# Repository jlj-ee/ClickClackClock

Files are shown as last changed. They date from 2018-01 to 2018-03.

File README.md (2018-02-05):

# ClickClackClock
This was a hobby project to create an impractically loud and large clock constructed from salvaged electromechanical seven-segment flip digits (also known as vane displays). To be slightly less obnoxious, the clock automatically sleeps in dark rooms, and wakes up with the correct time when exposed to light -- great for people who like to wake up with the dawn! 
<!--- The clock can also be put into a countdown/stopwatch mode, appropriate for games, New Year's Eve, the apocalypse, etc. --->

The [flip digits](http://www.scoretronics.com/components/Digits_Brochure.pdf) came from a retired aquatics scoreboard/timing system. The segments change position when current is pulsed through a magnetic coil. 

## Software
__Required dependencies:__

**_More info TBA_**

## CAD Contents
We designed custom 2-layer PCBs for this project using [Eagle](https://www.autodesk.com/products/eagle/overview) and fabbed them using [OSHPark](https://oshpark.com/), with all through-hole components for ease of assembly:
- __clock_driver_board:__ Drives a single digit, and can be daisy-chained together for as many digits as needed.
- __clock_motherboard:__ Slightly larger than the Arduino UNO but with the same microcontroller and pad layout for future shield compatibility. Integrates the standard DS1307 RTC on the board and controls the whole system - digit drivers, buttons, photoresistor, etc.
- __clock_system:__ Schematic that describes the overall system of PCBs and auxiliary components.

## Assembly
The digits are supported in a frame made from MDF. 

**_More info TBA_**

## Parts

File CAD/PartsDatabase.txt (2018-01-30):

Mfg Part Num	Mfg Name	VID	Vendor Part Num	Description	Pkg Code
EEU-TP1E202S	Panasonic	ME	667-EEU-TP1E202S	Aluminum Electrolytic Capacitors - Leaded Aluminum Electrolytic Capacitors - Leaded 2000uF 25volts AEC-Q200	
CFR-25JR-52-470R	Yageo	ME	603-CFR-25JR-52470R	Carbon Film Resistors - Through Hole Carbon Film Resistors - Through Hole 470ohm 1/4W 5%	
1546551-3	TE Connectivity	ME	571-1546551-3	"Fixed Terminal Blocks 3P,STRAIGHT SIDE ENTRY,3.5MM"	
826631-4	TE Connectivity	ME	571-826631-4	Headers & Wire Housings 1X04 POS R/A AU	
21RZ310-RC	Xicon	ME	21RZ310-RC	Multilayer Ceramic Capacitors MLCC - Leaded .1uF 50volts Z5U 20% 2.5mm L/S	
CD74HC4050E	Texas Instruments	ME	595-CD74HC4050E	Buffers & Line Drivers Hex Non-Inverting	
MIC5891YN	Microchip Technology / Micrel	ME	998-MIC5891YN	Latches 8-Bit Serial Input Latched Driver	
WP7113SRD/D	Kingbright	ME	604-WP7113SRD/D	Standard LEDs - Through Hole RED DIFFUSED	
ATMEGA328P-PU	Microchip Technology / Atmel	ME	556-ATMEGA328P-PU	8-bit Microcontrollers - MCU 32KB In-system Flash 20MHz 1.8V-5.5V	
4828-3004-CP	3M	ME	517-4828-3004-CP	"IC & Component Sockets SOCKET 28POS .3"" IC OPEN FRAME"	
DS1307+	Maxim Integrated	ME	700-DS1307	Real Time Clock 64x8 Serial I2C RTC	
LM1086CT-5.0/NOPB	Texas Instruments	ME	926-LM1086CT50NOPB	IC REG LINEAR 5.0V 1.5A TO220-3	
LM1086CT-3.3/NOPB	Texas Instruments	ME	926-LM1086CT-3.3NOPB	IC REG LINEAR 3.3V 1.5A TO220-3	
3001	Keystone Electronics	ME	534-3001	HOLDER BATTERY COIN 12MM DIA THM	
CR1220	FDK America	ME	658-CR1220	BATTERY LITHIUM 3V COIN 12.5MM	
WP7113SYD	Kingbright	ME	604-WP7113SYD	Standard LEDs - Through Hole YELLOW DIFFUSED	
K220J15C0GF5TL2	Vishay / BC Components	ME	594-K220J15C0GF5TL2	Multilayer Ceramic Capacitors MLCC - Leaded 22pF 50volts 5% C0G 2.5mm LS	
K104K15X7RF53L2	Vishay / BC Components	ME	594-K104K15X7RF53L2	Multilayer Ceramic Capacitors MLCC - Leaded 0.1uF 50volts 10% X7R 2.5mm LS	
EEU-FR1H220B	Panasonic	ME	667-EEU-FR1H220B	CAP ALUM 22UF 20% 50V RADIAL	
ECA-1CM470I	Panasonic	ME	667-ECA-1CM470I	CAP ALUM 47UF 20% 16V RADIAL	
1N4001-TP	Micro Commercial Co.	ME	833-1N4001-TP	DIODE GEN PURP 50V 1A DO41	
AB38T-32.768KHZ	Abracon LLC	ME	815-AB38T-32.768KHZ	CRYSTAL 32.7680KHZ 12.5PF T/H	
CFR-25JB-52-1K	Yageo	ME	603-CFR-25JB-1K0	Carbon Film Resistors - Through Hole Carbon Film Resistors - Through Hole 1kohm 1/4W 5%	
CFR-25JB-52-4K7	Yageo	ME	603-CFR-25JB-52-4K7	Carbon Film Resistors - Through Hole Carbon Film Resistors - Through Hole 4.7kohm 1/4W 5%	
CFR-25JB-52-10K	Yageo	ME	603-CFR-25JB-52-10K	Carbon Film Resistors - Through Hole Carbon Film Resistors - Through Hole 10kohm 1/4W 5%	
HC49US-16.000MABJ-UB	Citizen FineDevice	ME	695-HC49US-16-U	Crystals 16MHz 18pF HC49S THROUGH HOLE	
PJ-102AH	CUI Inc.	ME	490-PJ-102AH	CONN PWR JACK 2X5.5MM SOLDER	
B3F-1000	Omron Electronics	ME	653-B3F-1000	Tactile Switches 6X6 Flat 4.3mm Btn Force 100g w/o Grd	
68001-403HLF	Amphenol FCI	ME	649-68001-403HLF	CONN HEADER 3 POS .100	
68000-406HLF	Amphenol FCI	ME	649-68000-406HLF	CONN HEADER 6 POS .100	
382811-8	TE Connectivity	ME	571-3828118	"SHUNT, ECON, PHBR 5AU, BLACK"	
9900	Keystone Electronics	ME	534-9900	Screws & Fasteners 4-40 X 1/4 SCREW	
2200	Keystone Electronics	ME	534-2201	Standoffs & Spacers HEX .250X.250 ALUM

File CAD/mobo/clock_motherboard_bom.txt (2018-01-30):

Part	Value	Attributes	Package	Description	Part Num	Mfg Name	VID	Vendor Part Num	Description	Pkg Code	XREF
BAT	CR1220		CR1220-THM	CR1216/CR1220/CR1225 12mm 3V lithium coin cell	3001	Keystone Electronics	ME	534-3001	HOLDER BATTERY COIN 12MM DIA THM	*	REF14
BATTERY	CH23-1220LF		CH23-1220LF	Battary Holder, DIP, 12mm	CR1220	FDK America	ME	658-CR1220	BATTERY LITHIUM 3V COIN 12.5MM	*	REF15
C1	0.1uF		C025-025X050	CAPACITOR, American symbol	21RZ310-RC	Xicon	ME	21RZ310-RC	Multilayer Ceramic Capacitors MLCC - Leaded .1uF 50volts Z5U 20% 2.5mm L/S	*	REF5
C2	0.1uF		C025-025X050	CAPACITOR, American symbol	21RZ310-RC	Xicon	ME	21RZ310-RC	Multilayer Ceramic Capacitors MLCC - Leaded .1uF 50volts Z5U 20% 2.5mm L/S	*	REF5
C3	0.1uF		C025-025X050	CAPACITOR, American symbol	21RZ310-RC	Xicon	ME	21RZ310-RC	Multilayer Ceramic Capacitors MLCC - Leaded .1uF 50volts Z5U 20% 2.5mm L/S	*	REF5
C4	0.1uF		C025-025X050	CAPACITOR, American symbol	21RZ310-RC	Xicon	ME	21RZ310-RC	Multilayer Ceramic Capacitors MLCC - Leaded .1uF 50volts Z5U 20% 2.5mm L/S	*	REF5
C5	22pF		C025-025X050	CAPACITOR, American symbol	K220J15C0GF5TL2	Vishay / BC Components	ME	594-K220J15C0GF5TL2	Multilayer Ceramic Capacitors MLCC - Leaded 22pF 50volts 5% C0G 2.5mm LS	*	REF17
C6	22pF		C025-025X050	CAPACITOR, American symbol	K220J15C0GF5TL2	Vishay / BC Components	ME	594-K220J15C0GF5TL2	Multilayer Ceramic Capacitors MLCC - Leaded 22pF 50volts 5% C0G 2.5mm LS	*	REF17
C7	0.1uF		C025-025X050	CAPACITOR, American symbol	21RZ310-RC	Xicon	ME	21RZ310-RC	Multilayer Ceramic Capacitors MLCC - Leaded .1uF 50volts Z5U 20% 2.5mm L/S	*	REF5
C8	22uF/25V		E2,5-6	POLARIZED CAPACITOR, American symbol	EEU-FR1H220B	Panasonic	ME	667-EEU-FR1H220B	CAP ALUM 22UF 20% 50V RADIAL	*	REF19
C9	50uF/6V		E2,5-6	POLARIZED CAPACITOR, American symbol	ECA-1CM470I	Panasonic	ME	667-ECA-1CM470I	CAP ALUM 47UF 20% 16V RADIAL	*	REF20
C10	50uF/6V		E2,5-6	POLARIZED CAPACITOR, American symbol	ECA-1CM470I	Panasonic	ME	667-ECA-1CM470I	CAP ALUM 47UF 20% 16V RADIAL	*	REF20
D1	1N4001		DO41-10	DIODE	1N4001-TP	Micro Commercial Co.	ME	833-1N4001-TP	DIODE GEN PURP 50V 1A DO41	*	REF21
D2	RED		LED3MM	LED	WP7113SRD/D	Kingbright	ME	604-WP7113SRD/D	Standard LEDs - Through Hole RED DIFFUSED	*	REF8
D3	YELLOW		LED3MM	LED	WP7113SYD	Kingbright	ME	604-WP7113SYD	Standard LEDs - Through Hole YELLOW DIFFUSED	*	REF16
IC1	LM1086CT-5.0		78XXS	VOLTAGE REGULATOR	LM1086CT-5.0/NOPB	Texas Instruments	ME	926-LM1086CT50NOPB	IC REG LINEAR 5.0V 1.5A TO220-3	*	REF12
IC2	LM1086CT-3.3		78XXS	VOLTAGE REGULATOR	LM1086CT-3.3/NOPB	Texas Instruments	ME	926-LM1086CT-3.3NOPB	IC REG LINEAR 3.3V 1.5A TO220-3	*	REF13
J1	2.1MMJACK		PJ-102A		PJ-102AH	CUI Inc.	ME	490-PJ-102AH	CONN PWR JACK 2X5.5MM SOLDER	*	REF27
J2	PWR_SEL		JUMP	JUMPER header	382811-8	TE Connectivity	ME	571-3828118	SHUNT, ECON, PHBR 5AU, BLACK	*	REF31
JP2	FTDI_DEVICE		FTDI_DEVICE_SIDE	Connector which mates to FTDI basic or FTDI cable.	68000-406HLF	Amphenol FCI	ME	649-68000-406HLF	CONN HEADER 6 POS .100	*	REF30
JP3	PWR_OUT		SCREWTERMINAL-3.5MM-3	Header 3	1546551-3	TE Connectivity	ME	571-1546551-3	Fixed Terminal Blocks 3P,STRAIGHT SIDE ENTRY,3.5MM	*	REF3
JP4	PWR_SEL		1X03	PIN HEADER	68001-403HLF	Amphenol FCI	ME	649-68001-403HLF	CONN HEADER 3 POS .100	*	REF29
R1	4.7 K		0207/5V	RESISTOR, American symbol	CFR-25JB-52-4K7	Yageo	ME	603-CFR-25JB-52-4K7	Carbon Film Resistors - Through Hole Carbon Film Resistors - Through Hole 4.7kohm 1/4W 5%	*	REF24
R2	4.7 K		0207/5V	RESISTOR, American symbol	CFR-25JB-52-4K7	Yageo	ME	603-CFR-25JB-52-4K7	Carbon Film Resistors - Through Hole Carbon Film Resistors - Through Hole 4.7kohm 1/4W 5%	*	REF24
R3	1.0 K		0207/5V	RESISTOR, American symbol	CFR-25JB-52-1K	Yageo	ME	603-CFR-25JB-1K0	Carbon Film Resistors - Through Hole Carbon Film Resistors - Through Hole 1kohm 1/4W 5%	*	REF23
R4	1.0 K		0207/5V	RESISTOR, American symbol	CFR-25JB-52-1K	Yageo	ME	603-CFR-25JB-1K0	Carbon Film Resistors - Through Hole Carbon Film Resistors - Through Hole 1kohm 1/4W 5%	*	REF23
R5	10K		0207/5V	RESISTOR, American symbol	CFR-25JB-52-10K	Yageo	ME	603-CFR-25JB-52-10K	Carbon Film Resistors - Through Hole Carbon Film Resistors - Through Hole 10kohm 1/4W 5%	*	REF25
R6	4.7 K		0207/5V	RESISTOR, American symbol	CFR-25JB-52-4K7	Yageo	ME	603-CFR-25JB-52-4K7	Carbon Film Resistors - Through Hole Carbon Film Resistors - Through Hole 4.7kohm 1/4W 5%	*	REF24
RDIV	10K		0207/5V	RESISTOR, American symbol	CFR-25JB-52-10K	Yageo	ME	603-CFR-25JB-52-10K	Carbon Film Resistors - Through Hole Carbon Film Resistors - Through Hole 10kohm 1/4W 5%	*	REF25
S1	RESET		B3F-10XX	OMRON SWITCH	B3F-1000	Omron Electronics	ME	653-B3F-1000	Tactile Switches 6X6 Flat 4.3mm Btn Force 100g w/o Grd	*	REF28
SOCKET	ZIFSOCKET-28-3ZIFFSOCKET-28-3		DIL28-3-ZIF_SOCKET	Lever-action ZIF socket for 28-pin ICs	4828-3004-CP	3M	ME	517-4828-3004-CP	IC & Component Sockets SOCKET 28POS .3"" IC OPEN FRAME	*	REF10
STANDOFF1	STAND-OFF		STAND-OFF	#4 Stand Off	2200	Keystone Electronics	ME	534-2201	Standoffs & Spacers HEX .250X.250 ALUM	*	REF33
STANDOFF2	STAND-OFF		STAND-OFF	#4 Stand Off	2200	Keystone Electronics	ME	534-2201	Standoffs & Spacers HEX .250X.250 ALUM	*	REF33
STANDOFF3	STAND-OFF		STAND-OFF	#4 Stand Off	2200	Keystone Electronics	ME	534-2201	Standoffs & Spacers HEX .250X.250 ALUM	*	REF33
STANDOFF4	STAND-OFF		STAND-OFF	#4 Stand Off	2200	Keystone Electronics	ME	534-2201	Standoffs & Spacers HEX .250X.250 ALUM	*	REF33
STANDOFF5	STAND-OFF		STAND-OFF	#4 Stand Off	9900	Keystone Electronics	ME	534-9900	Screws & Fasteners 4-40 X 1/4 SCREW	*	REF32
STANDOFF6	STAND-OFF		STAND-OFF	#4 Stand Off	9900	Keystone Electronics	ME	534-9900	Screws & Fasteners 4-40 X 1/4 SCREW	*	REF32
STANDOFF7	STAND-OFF		STAND-OFF	#4 Stand Off	9900	Keystone Electronics	ME	534-9900	Screws & Fasteners 4-40 X 1/4 SCREW	*	REF32
STANDOFF8	STAND-OFF		STAND-OFF	#4 Stand Off	9900	Keystone Electronics	ME	534-9900	Screws & Fasteners 4-40 X 1/4 SCREW	*	REF32
U1	ATMEGA328P_PDIP		DIL28-3	uC used in the Arduino	ATMEGA328P-PU	Microchip Technology / Atmel	ME	556-ATMEGA328P-PU	8-bit Microcontrollers - MCU 32KB In-system Flash 20MHz 1.8V-5.5V	*	REF9
U2	DS1307		DIL08	DS1307	DS1307+	Maxim Integrated	ME	700-DS1307	Real Time Clock 64x8 Serial I2C RTC	*	REF11
Y1	16MHz		HC49US	Various standard crystals. Proven footprints.	HC49US-16.000MABJ-UB	Citizen FineDevice	ME	695-HC49US-16-U	Crystals 16MHz 18pF HC49S THROUGH HOLE	*	REF26
Y2	32.768		TC38H	CRYSTAL	AB38T-32.768KHZ	Abracon LLC	ME	815-AB38T-32.768KHZ	CRYSTAL 32.7680KHZ 12.5PF T/H	*	REF22

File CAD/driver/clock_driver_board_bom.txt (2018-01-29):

Part	Value	Attributes	Package	Description	Part Num	Mfg Name	VID	Vendor Part Num	Description	Pkg Code	XREF
C1	0.1uF		C2.5-2	CAPACITOR	21RZ310-RC	Xicon	ME	21RZ310-RC	Multilayer Ceramic Capacitors MLCC - Leaded .1uF 50volts Z5U 20% 2.5mm L/S	*	REF5
C2	0.1uF		C2.5-2	CAPACITOR	21RZ310-RC	Xicon	ME	21RZ310-RC	Multilayer Ceramic Capacitors MLCC - Leaded .1uF 50volts Z5U 20% 2.5mm L/S	*	REF5
C3	0.1uF		C2.5-2	CAPACITOR	21RZ310-RC	Xicon	ME	21RZ310-RC	Multilayer Ceramic Capacitors MLCC - Leaded .1uF 50volts Z5U 20% 2.5mm L/S	*	REF5
C4	2000uF		E7,5-16	POLARIZED CAPACITOR, American symbol	EEU-TP1E202S	Panasonic	ME	667-EEU-TP1E202S	Aluminum Electrolytic Capacitors - Leaded Aluminum Electrolytic Capacitors - Leaded 2000uF 25volts AEC-Q200	*	REF1
LED1			LED3MM	LED	WP7113SRD/D	Kingbright	ME	604-WP7113SRD/D	Standard LEDs - Through Hole RED DIFFUSED	*	REF8
P8			1X04_LONGPADS	Header 4	826631-4	TE Connectivity	ME	571-826631-4	Headers & Wire Housings 1X04 POS R/A AU	*	REF4
P9			1X04_LONGPADS	Header 4	826631-4	TE Connectivity	ME	571-826631-4	Headers & Wire Housings 1X04 POS R/A AU	*	REF4
P10			SCREWTERMINAL-3.5MM-3	Header 3	1546551-3	TE Connectivity	ME	571-1546551-3	Fixed Terminal Blocks 3P,STRAIGHT SIDE ENTRY,3.5MM	*	REF3
P11			SCREWTERMINAL-3.5MM-3	Header 3	1546551-3	TE Connectivity	ME	571-1546551-3	Fixed Terminal Blocks 3P,STRAIGHT SIDE ENTRY,3.5MM	*	REF3
R1	470Ohm		0204/7	RESISTOR, American symbol	CFR-25JR-52-470R	Yageo	ME	603-CFR-25JR-52470R	Carbon Film Resistors - Through Hole Carbon Film Resistors - Through Hole 470ohm 1/4W 5%	*	REF2
U1	MIC5891		DIL16	8-Bit Serial-Input Latched Source Driver	MIC5891YN	Microchip Technology / Micrel	ME	998-MIC5891YN	Latches 8-Bit Serial Input Latched Driver	*	REF7
U2	MIC5891		DIL16	8-Bit Serial-Input Latched Source Driver	MIC5891YN	Microchip Technology / Micrel	ME	998-MIC5891YN	Latches 8-Bit Serial Input Latched Driver	*	REF7
U3	HEX_CONVERTERDIP16		DIL16	74HC4050 Hex Buffer Level Shifter SMD SO016	CD74HC4050E	Texas Instruments	ME	595-CD74HC4050E	Buffers & Line Drivers Hex Non-Inverting	*	REF6

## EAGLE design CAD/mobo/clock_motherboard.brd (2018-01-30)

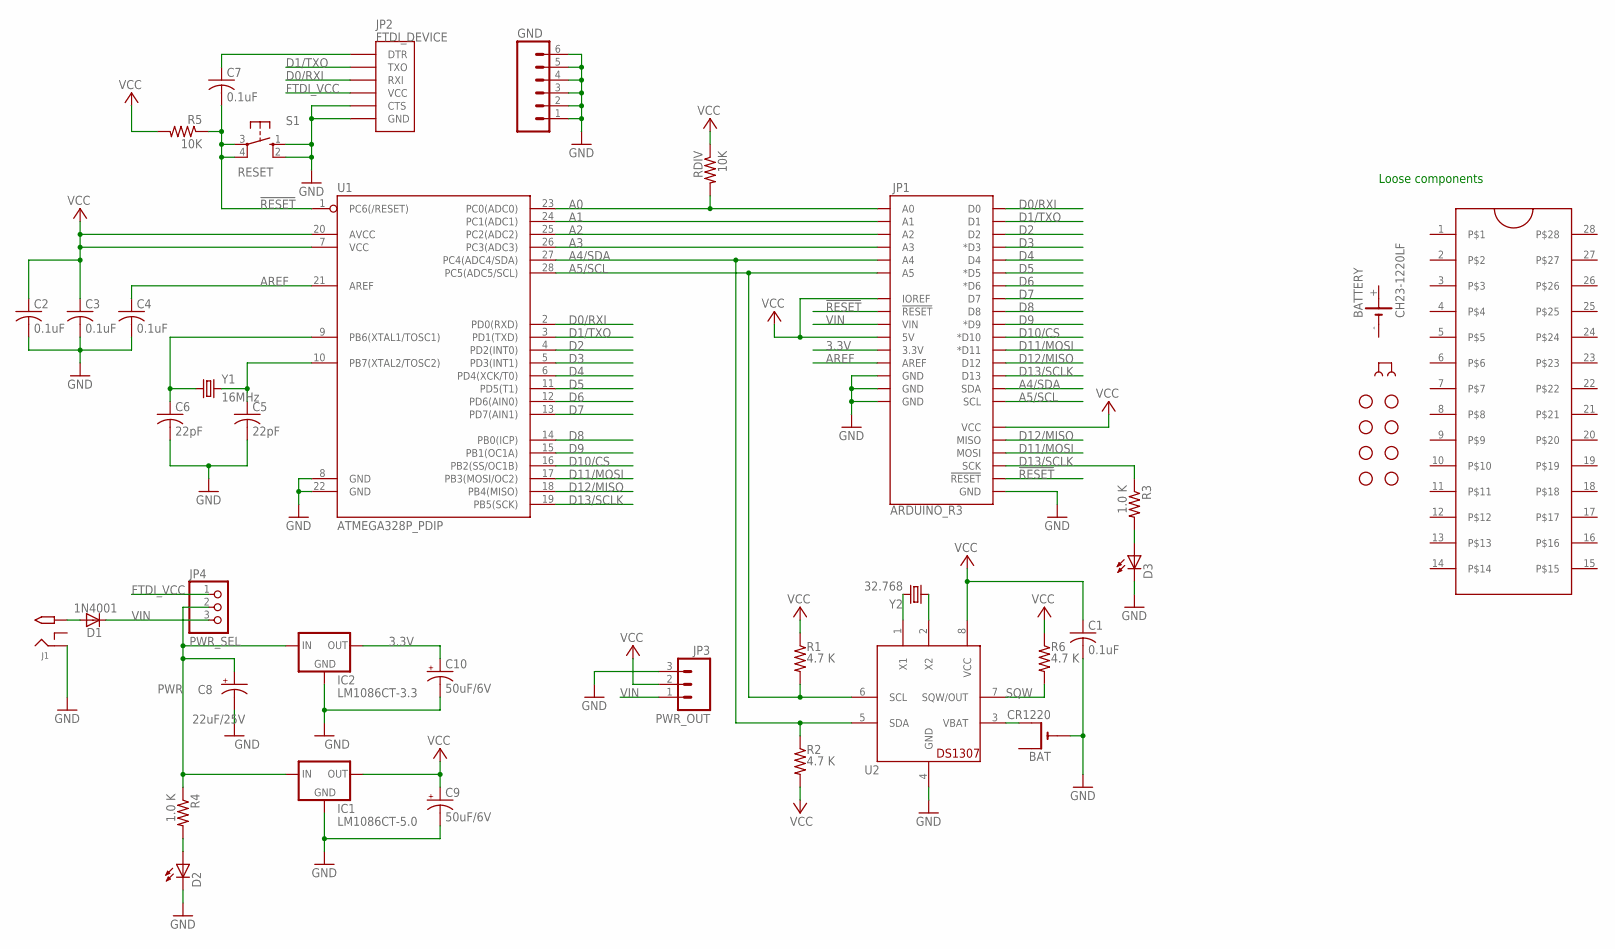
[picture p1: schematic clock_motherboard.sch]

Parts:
BAT: CR1220; CR1220-THM; PARTNO 3001
BATTERY: CH23-1220LF; PARTNO CR1220
C1, C2, C3, C4, C7: 0.1uF; C025-025X050; PARTNO 21RZ310-RC
C5, C6: 22pF; C025-025X050; PARTNO K220J15C0GF5TL2
C8: 22uF/25V; E2,5-6; PARTNO EEU-FR1H220B
C9, C10: 50uF/6V; E2,5-6; PARTNO ECA-1CM470I
D1: 1N4001; DO41-10; PARTNO 1N4001-TP
D2: RED; LED3MM; PARTNO WP7113SRD/D
D3: YELLOW; LED3MM; PARTNO WP7113SYD
GND: M06NO_SILK_FEMALE_PTH; 1X06_NO_SILK
IC1: LM1086CT-5.0; 78XXS; PARTNO LM1086CT-5.0/NOPB
IC2: LM1086CT-3.3; 78XXS; PARTNO LM1086CT-3.3/NOPB
J1: 2.1MMJACK; PJ-102A; PARTNO PJ-102AH
J2: PWR_SEL; JUMP; PARTNO 382811-8
JP1: ARDUINO_R3
JP2: FTDI_DEVICE; FTDI_DEVICE_SIDE; PARTNO 68000-406HLF
JP3: PWR_OUT; SCREWTERMINAL-3.5MM-3; PARTNO 1546551-3
JP4: PWR_SEL; 1X03; PARTNO 68001-403HLF
R1, R2, R6: 4.7 K; 0207/5V; PARTNO CFR-25JB-52-4K7
R3, R4: 1.0 K; 0207/5V; PARTNO CFR-25JB-52-1K
R5: 10K; 0207/5V; PARTNO CFR-25JB-52-10K
RDIV: 10K; 0207/5V; PARTNO CFR-25JB-52-10K
S1: RESET; B3F-10XX
SOCKET: ZIFSOCKET-28-3ZIFFSOCKET-28-3; DIL28-3-ZIF_SOCKET; PARTNO 4828-3004-CP
STANDOFF1, STANDOFF2, STANDOFF3, STANDOFF4: STAND-OFF; PARTNO 2200
STANDOFF5, STANDOFF6, STANDOFF7, STANDOFF8: STAND-OFF; PARTNO 9900
U1: ATMEGA328P_PDIP; DIL28-3; PARTNO ATMEGA328P-PU
U2: DS1307; DIL08; PARTNO DS1307+
Y1: 16MHz; HC49US; PARTNO HC49US-16.000MABJ-UB
Y2: 32.768; TC38H; PARTNO AB38T-32.768KHZ

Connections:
3.3V: C10.+, IC2.OUT, JP1.3.3V
!RESET: C7.2, JP1.RESET@1 (!RESET!), JP1.RESET@2 (!RESET!), R5.1, S1.3, S1.4 (P1), U1.1 (PC6(/RESET))
A0: JP1.A0, RDIV.2, U1.23 (PC0(ADC0))
A1: JP1.A1, U1.24 (PC1(ADC1))
A2: JP1.A2, U1.25 (PC2(ADC2))
A3: JP1.A3, U1.26 (PC3(ADC3))
A4/SDA: JP1.A4, JP1.SDA, R2.1, U1.27 (PC4(ADC4/SDA)), U2.5 (SDA)
A5/SCL: JP1.A5, JP1.SCL, R1.2, U1.28 (PC5(ADC5/SCL)), U2.6 (SCL)
AREF: C4.1, JP1.AREF, U1.21 (AREF)
D0/RXI: JP1.D0, JP2.P$3 (RXI), U1.2 (PD0(RXD))
D1/TXO: JP1.D1, JP2.P$2 (TXO), U1.3 (PD1(TXD))
D2: JP1.D2, U1.4 (PD2(INT0))
D3: JP1.D3 (*D3), U1.5 (PD3(INT1))
D4: JP1.D4, U1.6 (PD4(XCK/T0))
D5: JP1.D5 (*D5), U1.11 (PD5(T1))
D6: JP1.D6 (*D6), U1.12 (PD6(AIN0))
D7: JP1.D7, U1.13 (PD7(AIN1))
D8: JP1.D8, U1.14 (PB0(ICP))
D9: JP1.D9 (*D9), U1.15 (PB1(OC1A))
D10/CS: JP1.D10 (*D10), U1.16 (PB2(SS/OC1B))
D11/MOSI: JP1.D11 (*D11), JP1.MOSI, U1.17 (PB3(MOSI/OC2))
D12/MISO: JP1.D12, JP1.MISO, U1.18 (PB4(MISO))
D13/SCLK: JP1.D13, JP1.SCK, R3.1, U1.19 (PB5(SCK))
FTDI_VCC: JP2.P$4 (VCC), JP4.1
GND: BAT.-, C1.2, C2.2, C3.2, C4.2, C5.2, C6.2, C8.-, C9.-, C10.-, D2.K (C), D3.K (C), GND.1, GND.2, GND.3, GND.4, GND.5, GND.6, IC1.GND, IC2.GND, J1.RING, JP1.GND@1 (GND), JP1.GND@2 (GND), JP1.GND@3 (GND), JP1.GND@4 (GND), JP2.P$5 (CTS), JP2.P$6 (GND), JP3.3, S1.1 (S), S1.2 (S1), U1.8 (GND), U1.22 (GND), U2.4 (GND)
unnamed: C6.1, U1.9 (PB6(XTAL1/TOSC1)), Y1.1
unnamed: C5.1, U1.10 (PB7(XTAL2/TOSC2)), Y1.2
unnamed: C7.1, JP2.P$1 (DTR)
unnamed: D3.A, R3.2
unnamed: D2.A, R4.2
unnamed: U2.1 (X1), Y2.2
unnamed: U2.2 (X2), Y2.1
unnamed: D1.A, J1.TIP
unnamed: BAT.+2 (+1), U2.3 (VBAT)
PWR: C8.+, IC1.IN, IC2.IN, JP4.2, R4.1
SQW: R6.2, U2.7 (SQW/OUT)
VCC: C1.1, C2.1, C3.1, C9.+, IC1.OUT, JP1.5V, JP1.IOREF, JP1.VCC, JP3.2, R1.1, R2.2, R5.2, R6.1, RDIV.1, U1.7 (VCC), U1.20 (AVCC), U2.8 (VCC)
VIN: D1.C, JP1.VIN, JP3.1, JP4.3

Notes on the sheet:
Loose components

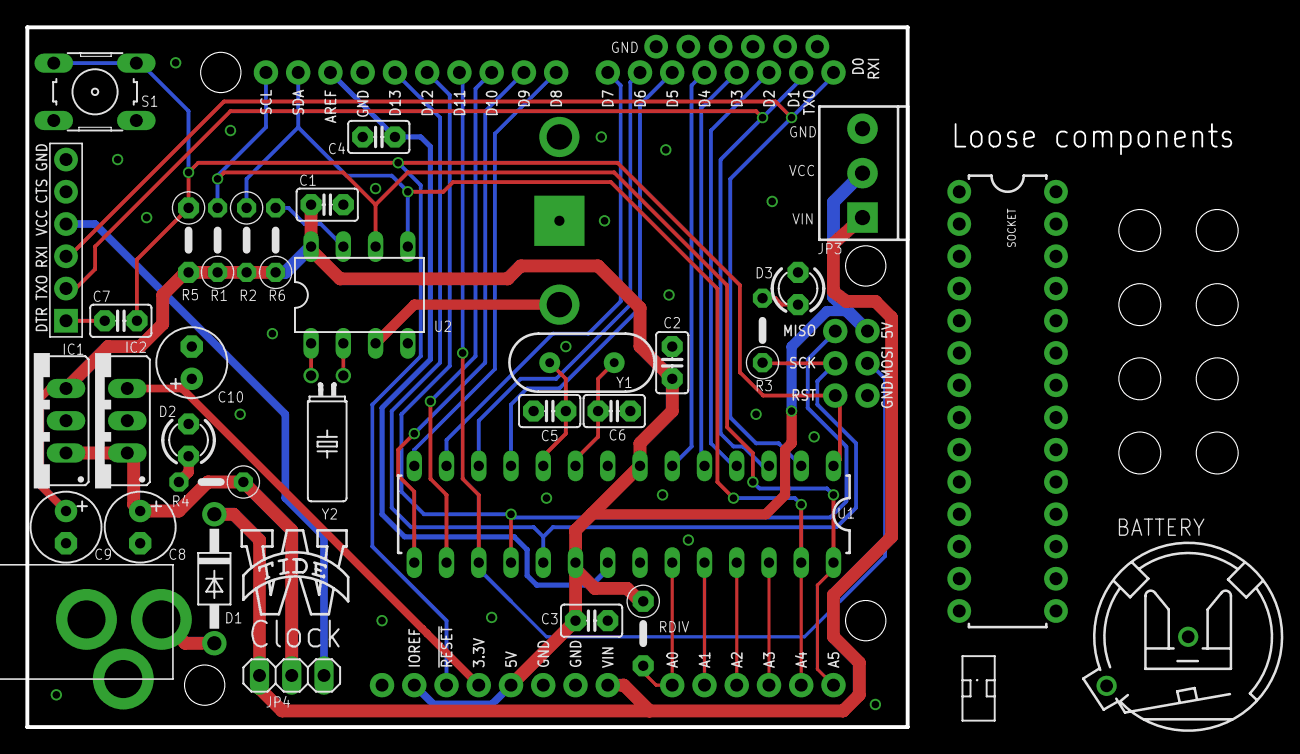
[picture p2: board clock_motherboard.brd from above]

Board: 2 copper layers, 69.3 x 55.1 mm, 45 parts (1 on the bottom side), 38 nets.

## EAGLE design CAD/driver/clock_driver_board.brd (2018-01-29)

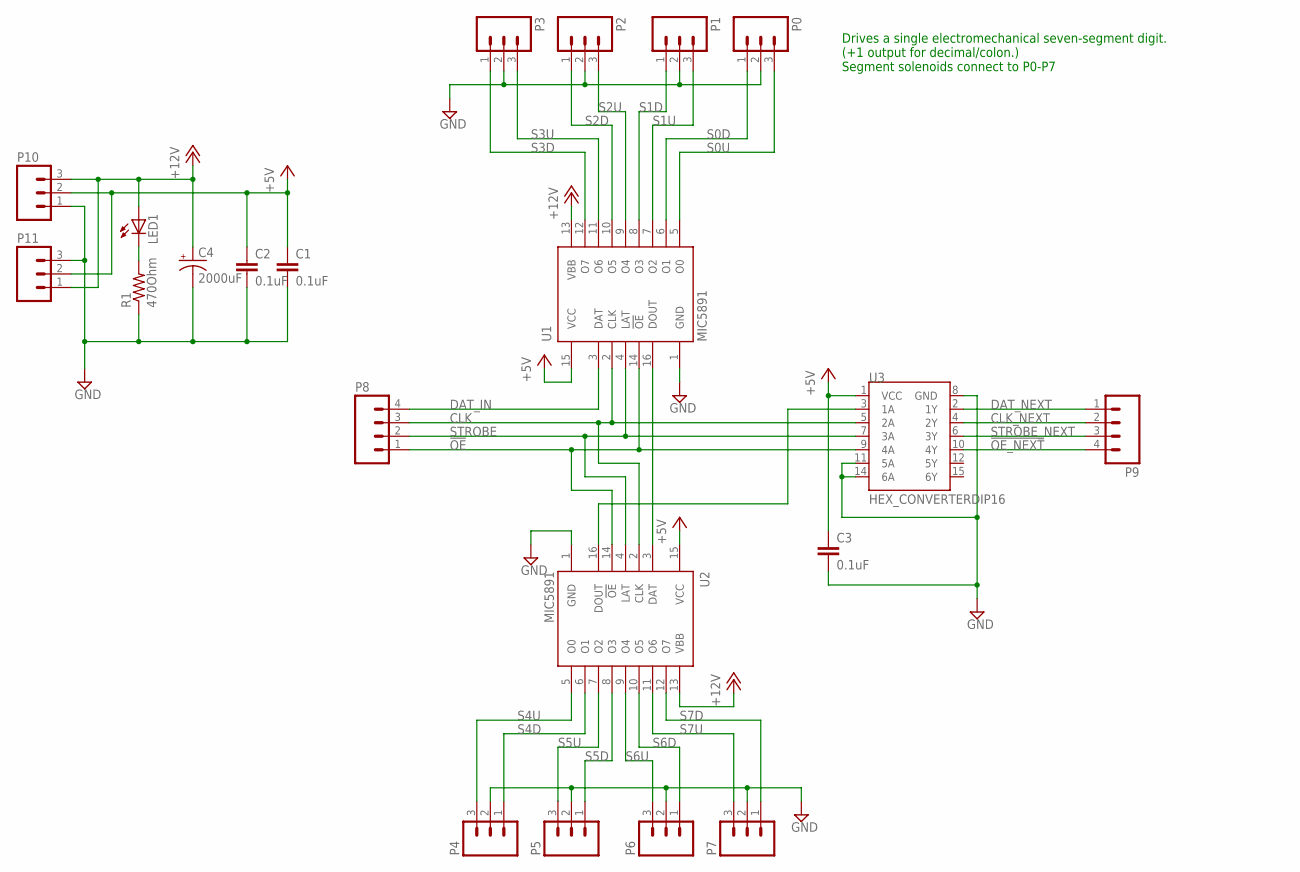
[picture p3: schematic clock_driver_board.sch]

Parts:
C1, C2, C3: 0.1uF; C2.5-2; PARTNO 21RZ310-RC
C4: 2000uF; E7,5-16; PARTNO EEU-TP1E202S
LED1: LED3MM; PARTNO WP7113SRD/D
P0, P1, P2, P3, P4, P5, P6, P7: M03LONGPADS; 1X03_LONGPADS
P8, P9: M04LONGPADS; 1X04_LONGPADS; PARTNO 826631-4
P10, P11: M03SCREW; SCREWTERMINAL-3.5MM-3; PARTNO 1546551-3
R1: 470Ohm; 0204/7; PARTNO CFR-25JR-52-470R
U1, U2: MIC5891; DIL16; PARTNO MIC5891YN
U3: HEX_CONVERTERDIP16; DIL16; PARTNO CD74HC4050E

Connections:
!OE: P8.1, U1.14 (!OE), U2.14 (!OE), U3.9 (4A)
!OE_NEXT: P9.4, U3.10 (4Y)
+5V: C1.1, C2.1, C3.1, P10.2, P11.2, U1.15 (VCC), U2.15 (VCC), U3.1 (VCC)
+12V: C4.+, LED1.A, P10.3, P11.1, U1.13 (VBB), U2.13 (VBB)
CLK: P8.3, U1.2 (CLK), U2.2 (CLK), U3.5 (2A)
CLK_NEXT: P9.2, U3.4 (2Y)
DAT_IN: P8.4, U1.3 (DAT)
DAT_NEXT: P9.1, U3.2 (1Y)
GND: C1.2, C2.2, C3.2, C4.-, P0.2, P1.2, P2.2, P3.2, P4.2, P5.2, P6.2, P7.2, P10.1, P11.3, R1.1, U1.1 (GND), U2.1 (GND), U3.8 (GND), U3.11 (5A), U3.14 (6A)
LEDR: LED1.K (C), R1.2
unnamed: U1.16 (DOUT), U2.3 (DAT)
unnamed: U2.16 (DOUT), U3.3 (1A)
S0D: P0.1, U1.6 (O1)
S0U: P0.3, U1.5 (O0)
S1D: P1.1, U1.8 (O3)
S1U: P1.3, U1.7 (O2)
S2D: P2.1, U1.10 (O5)
S2U: P2.3, U1.9 (O4)
S3D: P3.1, U1.12 (O7)
S3U: P3.3, U1.11 (O6)
S4D: P4.1, U2.6 (O1)
S4U: P4.3, U2.5 (O0)
S5D: P5.1, U2.8 (O3)
S5U: P5.3, U2.7 (O2)
S6D: P6.1, U2.10 (O5)
S6U: P6.3, U2.9 (O4)
S7D: P7.1, U2.12 (O7)
S7U: P7.3, U2.11 (O6)
STROBE: P8.2, U1.4 (LAT), U2.4 (LAT), U3.7 (3A)
STROBE_NEXT: P9.3, U3.6 (3Y)

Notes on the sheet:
Drives a single electromechanical seven-segment digit. (+1 output for decimal/colon.) Segment solenoids connect to P0-P7

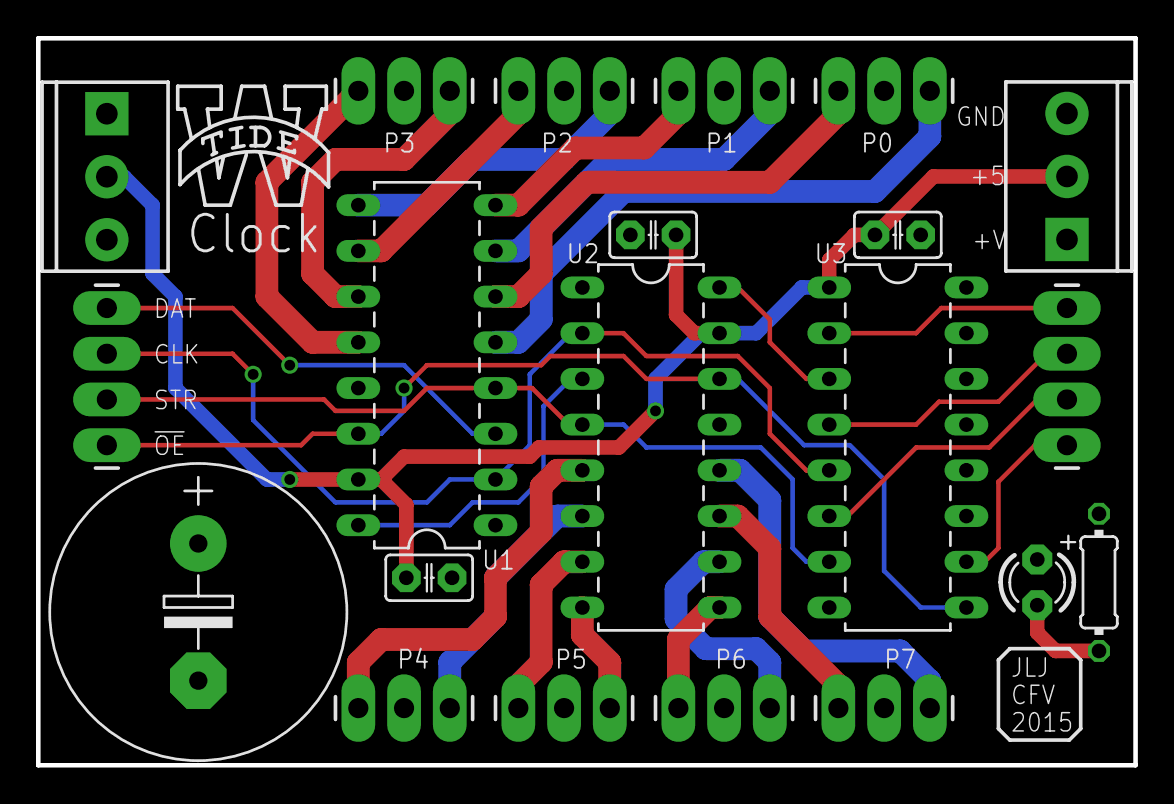
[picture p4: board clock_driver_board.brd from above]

Board: 2 copper layers, 61.0 x 40.4 mm, 21 parts (0 on the bottom side), 30 nets.

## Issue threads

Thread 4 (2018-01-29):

Add BOMs

jlj-ee, 2018-01-29:
Add BOMs:
- [x] Driver board
- [x] Motherboard

jlj-ee, 2018-02-01:
- [ ] Add system BOM (switches, photoresistor, PCBs, etc.)

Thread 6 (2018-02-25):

FTDI cannot be used to power the board during programming

jlj-ee, 2018-02-25:
The goal was to allow the PWR_SEL jumper to use the FTDI VCC to power the board during programming. The existing design, however, does not properly support this.

The power select jumper can feed the FTDI VCC to the 5V and 3.3V regulator inputs. But since the FTDI VCC will be either 5V or 3.3V, this will not work, as the LM7805 input voltage must be >7.5V. We also cannot bypass the regulators by jumping FTDI VCC to the 5V/VCC pin, since this will backfeed the LM7805 regulator.

This would need to be fixed in a future board revision.

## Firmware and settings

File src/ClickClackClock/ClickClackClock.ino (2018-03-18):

#include <Arduino.h>
#include "EnableInterrupt.h"
#include "RTClib.h"
#include "SerialClockDisplay.h"

/*===========================================================================*/
// Macros for debug
#define DEBUG 1  // Set to 0 to disable debug functions

#define debug_start(baud)          \
  do {                             \
    if (DEBUG) Serial.begin(baud); \
  } while (0)
#define debug_println(...)                  \
  do {                                      \
    if (DEBUG) Serial.println(__VA_ARGS__); \
  } while (0)
#define debug_print(...)                  \
  do {                                    \
    if (DEBUG) Serial.print(__VA_ARGS__); \
  } while (0)
#define debug_printDisplay()   \
  do {                         \
    if (DEBUG) printDisplay(); \
  } while (0)

/*===========================================================================*/
// Some enum definitions for convenience

// Output pin designations
typedef enum eOutputPins {
  kLeftEnPin = 9,    //!< Active-low output enable pin (!OE) for left side
  kRightEnPin = 10,  //!< Active-low output enable pin (!OE) for right side
  kStrobePin = 11,   //!< Active-high strobe pin (latch) for serial data
  kClockPin = 12,    //!< Active-high clock pin for serial data
  kDataPin = 13      //!< Data pin for serial data
} OutputPins;

// Input pin designations
typedef enum eInputPin {
  kClockModePin = 2,
  kCountModePin = 3,
  kCtrl1Pin = 4,
  kCtrl2Pin = 5,
  kUpPin = 6,
  kDownPin = 7
} InputPins;

// Operating modes
typedef enum eModes {
  kModeClock,
  kModeClockSetHour,
  kModeClockSetMinute,
  kModeStopwatchSet,
  kModeStopwatchRun,
  kModeStopwatchPause,
  kModeTimerSet,
  kModeTimerRun,
  kModeTimerPause
} Modes;

/*============================================================================*/
// Local constants and variables
const uint8_t kInputPins[] = {kClockModePin, kCountModePin, kCtrl1Pin,
                              kCtrl1Pin,     kUpPin,        kDownPin};
int nInputPins = sizeof(kInputPins) / sizeof(kInputPins[0]);
DateTime last_time, current_time;
bool update_left, update_right;
RTC_DS1307 rtc;
const SerialDisplayConfig kConfig = {.data_pin = kDataPin,
                                     .clock_pin = kClockPin,
                                     .strobe_pin = kStrobePin,
                                     .leften_pin = kLeftEnPin,
                                     .righten_pin = kRightEnPin,
                                     .clock_period_us = 4,
                                     .en_pulse_ms = 200,
                                     .strobe_pol = kActiveHigh,
                                     .en_pol = kActiveLow};
SerialClockDisplay display;
volatile Modes current_mode;
volatile int light_threshold;

/*============================================================================*/
void setup() {
  debug_start(9600);

  display.begin(&kConfig);

  // Set up input pins
  for (int i = 0; i < nInputPins; i++) {
    pinMode(kInputPins[i], INPUT_PULLUP);
    enableInterrupt(kInputPins[i] | PINCHANGEINTERRUPT, buttonHandler, FALLING);
  }

  rtc.begin();  // Always returns true
  if (!rtc.isrunning()) {
    debug_println("RTC is NOT running! :(");
  } else {
    debug_println("RTC is running! :)");
  }
  // Set the RTC to the date & time this sketch was compiled:
  rtc.adjust(DateTime(F(__DATE__), F(__TIME__)));
  current_mode = kModeClock;
}

void buttonHandler() {}

void loop() {
  current_time = rtc.now();
  update_left = false;
  update_right = false;

  if (current_mode == kModeClock) {
    if (last_time.hour() != current_time.hour()) {
      update_left = true;
    }
    if (last_time.minute() != current_time.minute()) {
      update_right = true;
    }
    display.writeBufferTime(militaryToStandard(current_time.hour()),
                            current_time.minute());
    display.displayBuffer(update_left, update_right);
  }
  last_time = current_time;
  delay(500);
}

uint8_t militaryToStandard(uint8_t hour) {
  hour = hour % 12;
  if (hour == 0) hour = 12;
  return hour;
}

void printDisplay() {
  Segments* buffer = display.readDisplay();
  Serial.print(buffer[0], HEX);
  Serial.print(" ");
  Serial.print(buffer[1], HEX);
  Serial.print(" : ");
  Serial.print(buffer[2], HEX);
  Serial.print(" ");
  Serial.println(buffer[3], HEX);
}

// // Sets hour/minute digits to blank until it's light out
// void blackOut(bool h, bool m) {
//   for (int i=0; i<4; i++) {
//     shiftDigit(10,0);
//   }
//   flipLatch();
//   switchHM(h,m);
//   while (analogRead(A0) > LIGHT_TRIGGER) {
//     delay(100);
//   }
//   shiftTime(current);
//   latchIn();
// }

//   // if (!isMilitaryTime) {
//   //   hour = (hour + 11) % 12 + 1; // Convert from 0-24 to 1-12
//   // }
// void loop() {
//   current = rtc.now();                           // Update the time
//   int light_reading = analogRead(A0);
//   Serial.println(light_reading);
//   if (light_reading > LIGHT_TRIGGER) {          // If it's dark out turn off
//     blackOut(1,1);
//   } else {
//     if (last.minute() != current.minute()) {     // If the time has changed, update!
//       shiftTime(current);
//       latchIn();
//     } else {
//       if (mode == 1) {
//         last = current;
//         blackOut(0,1);
//         while (mode == 1) {
//           //set minutes
//           if (digitalRead(upPin) == LOW) current = DateTime(current.unixtime()+60);
//           if (digitalRead(downPin) == LOW) current = DateTime(current.unixtime()-60);
//           if (last.unixtime() != current.unixtime()) {
//             rtc.adjust(current);
//             shiftTime(current);
//             latchIn();
//             last = current;
//           }
//         }
//         blackOut(1,0);
//         while (mode == 2) {
//           //set hours
//           if (digitalRead(upPin) == LOW) current = DateTime(current.unixtime()+3600);
//           if (digitalRead(downPin) == LOW) current = DateTime(current.unixtime()-3600);
//           if (last.unixtime() != current.unixtime()) {
//             rtc.adjust(current);
//             shiftTime(current);
//             latchIn();
//             last = current;
//           }
//         }
//         mode=0;
//         blackOut(1,1);
//       }
//     }
//   }
//   last = current;    // Save the time for next time
//   delay(500);        // Only do this every half second
// }

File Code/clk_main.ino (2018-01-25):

/*
PIN ORDER
dat
clk
str
oe
*/

#include <Wire.h>
#include "RTClib.h"

#define LIGHT_TRIGGER 850

DateTime last, current;
RTC_DS1307 rtc;

//Pins connected to !OE
int minuteOE = 13;
int hourOE = 9;
//Pin connected to strobe
int latchPin = 10;
////Pin connected to data
int dataPin = 11;
//Pin connected to clock
int clockPin = 12;

int setPin = 2;
int upPin = 3;
int downPin = 4;

// Mode 0 = Normal Operation
// Mode 1 = Set minutes
// Mode 2 = Set hours
// Mode 3/4 = Set Alarm
volatile int mode = 0;


byte segs[11] = {
  B11111100, // 0
  B01100000, // 1
  B11011010, // 2
  B11110010, // 3
  B01100110, // 4
  B10110110, // 5
  B10111110, // 6
  B11100000, // 7
  B11111110, // 8
  B11110110, // 9
  B00000000, // [blank]
};

word upDownBytes(byte segs) {
  byte nsegs = ~segs;
  word result = 0;
  for(int i = 15; i >= 0; i--) {
    result |= (segs >> i) & 1;
    result <<= 1;
    result |= (nsegs >> i) & 1;
    if (i != 0) {
      result <<= 1;
    }
  }
  Serial.println(segs, BIN);
  Serial.println(result, BIN);
  return result;
}

void setup() {
  Serial.begin(9600);
  
  pinMode(latchPin, OUTPUT);
  pinMode(clockPin, OUTPUT);
  pinMode(dataPin, OUTPUT);
  pinMode(minuteOE, OUTPUT);
  pinMode(hourOE, OUTPUT);
  pinMode(setPin, INPUT_PULLUP);
  pinMode(upPin, INPUT_PULLUP);
  pinMode(downPin, INPUT_PULLUP);
  digitalWrite(latchPin, LOW);
  digitalWrite(dataPin, LOW);
  digitalWrite(clockPin, LOW);
  digitalWrite(minuteOE, HIGH);
  digitalWrite(hourOE, HIGH);

  attachInterrupt(0, setTimeMode, FALLING);
  
  if (! rtc.begin()) {
    Serial.println("Couldn't find RTC");
    while (1);
  }
  if (! rtc.isrunning()) {
    Serial.println("RTC is NOT running!");
    // following line sets the RTC to the date & time this sketch was compiled
    // rtc.adjust(DateTime(F(__DATE__), F(__TIME__)));
  }
}

// Sets hour/minute digits to blank until it's light out
void blackOut(boolean h, boolean m) {
  for (int i=0; i<4; i++) {
    shiftDigit(10,0);
  }
  flipLatch();
  switchHM(h,m);
  while (analogRead(A0) > LIGHT_TRIGGER) {
    delay(100);
  }
  shiftTime(current);
  latchIn();
}

void setTimeMode() {
  switch (mode) {
    case 0:
      mode = 1;
      break;
    case 1:
      mode = 2;
      break;
    default:
      mode = 0;
      break;
  }
}

void loop() {
  current = rtc.now();                           // Update the time
  if (analogRead(A0) > LIGHT_TRIGGER) {          // If it's dark out turn off
    blackOut(1,1);
  } else {
    if (last.minute() != current.minute()) {     // If the time has changed, update!
      shiftTime(current);
      latchIn();
    } else {
      if (mode == 1) {
        last = current;
        blackOut(0,1);
        while (mode == 1) {
          //set minutes
          if (digitalRead(upPin) == LOW) current = DateTime(current.unixtime()+60);
          if (digitalRead(downPin) == LOW) current = DateTime(current.unixtime()-60);
          if (last.unixtime() != current.unixtime()) {
            rtc.adjust(current);
            shiftTime(current);
            latchIn();
            last = current;
          }
        }
        blackOut(1,0);
        while (mode == 2) {
          //set hours
          if (digitalRead(upPin) == LOW) current = DateTime(current.unixtime()+3600);
          if (digitalRead(downPin) == LOW) current = DateTime(current.unixtime()-3600);
          if (last.unixtime() != current.unixtime()) {
            rtc.adjust(current);
            shiftTime(current);
            latchIn();
            last = current;
          }
        }
        mode=0;
        blackOut(1,1);
      }
    }
  }
  last = current;                                // Save the time for next time
  delay(500);                                    // Only do this every half second
}

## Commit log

2018-01-25 Adding CAD files
    [clock_driver_board.brd, clock_driver_board.sch, clock_motherboard.brd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]
2018-01-25 Moving CAD files to subdirectory
    [clock_driver_board.brd, clock_driver_board.sch, clock_motherboard.brd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]
2018-01-25 Removing old CAD files
    [clock_driver_board.brd, clock_driver_board.sch, clock_motherboard.brd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]
2018-01-28 Update clk_main.ino
    Updated. Not sure if anything changed. But it's current as of today.
2018-01-29 Updating motherboard CAD files (OSHpark version)
    [clock_motherboard.brd, clock_motherboard.sch]
2018-01-29 Updated driver board CAD files for BOM
    [clock_driver_board.brd, clock_driver_board.sch]
2018-01-30 Adding updated part database and motherboard BOM, closes #4
    [clock_motherboard.brd, clock_motherboard.sch]
2018-02-01 Adding full-system schematic, closes #5
    [clock_system.sch]
2018-02-05 Started refactoring code to use new class
    [clock_system.sch]
2018-02-12 Fixes to account for renaming
    [ClickClackClock.ino]
2018-03-18 Significant changes to SerialClockDisplay to fix bugs found in hardware testing. Skeleton code added for timekeeping to main sketch.
    [ClickClackClock.ino, SerialClockDisplay.cpp]

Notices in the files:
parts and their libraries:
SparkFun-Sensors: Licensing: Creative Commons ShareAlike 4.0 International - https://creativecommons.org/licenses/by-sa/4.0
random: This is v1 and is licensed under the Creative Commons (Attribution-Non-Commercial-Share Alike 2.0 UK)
